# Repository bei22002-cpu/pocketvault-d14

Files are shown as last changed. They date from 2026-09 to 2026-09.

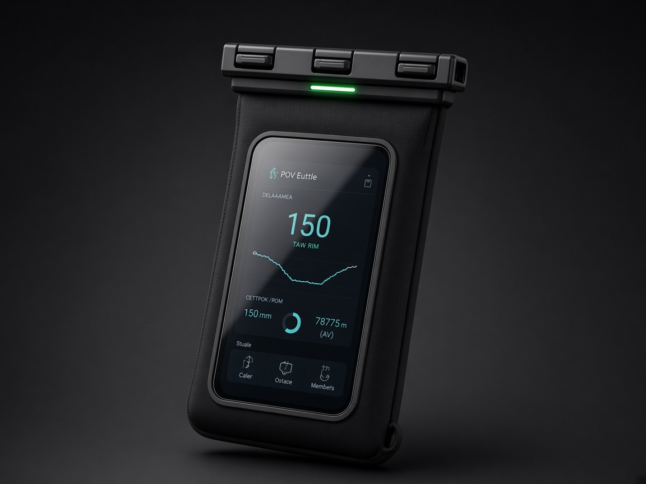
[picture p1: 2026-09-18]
blueprints/rolltop/renders/revD-hero-sealed.png

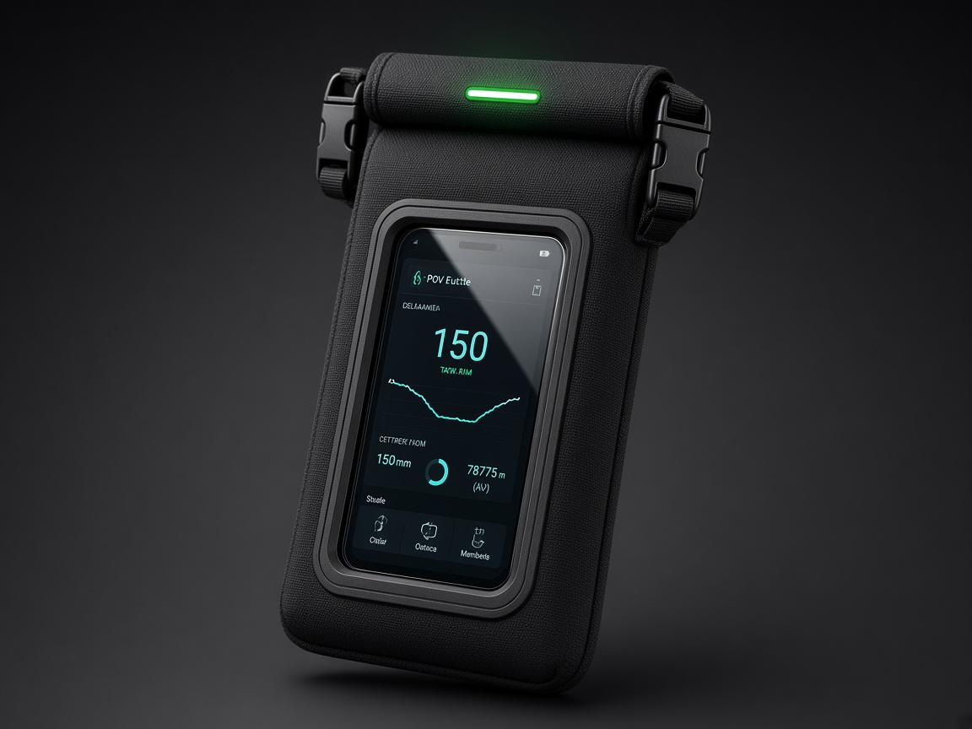
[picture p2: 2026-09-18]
blueprints/rolltop/renders/revB-hero-sealed.png

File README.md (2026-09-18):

# PocketVault · D14 Rolltop

**Live site: https://bei22002-cpu.github.io/pocketvault-d14/**

Product proposal, business model, and engineering package for the D14 Rolltop — a waterproof phone pouch you can use through the window, sold wholesale to retail stores. BYU-Idaho IBC, Oct 12 – Dec 16 window.

## Start here

| Link | What it is |
|---|---|
| [Product proposal deck](https://bei22002-cpu.github.io/pocketvault-d14/blueprints/d14-product-pitch.html) | 11 core slides + 3 appendix pages + business model canvas |
| [One-page pre-read](https://bei22002-cpu.github.io/pocketvault-d14/blueprints/d14-product-pitch-brief.html) | Decision request, trade-offs, economics, yes-vs-no. Print-ready |
| [Business model canvas](https://bei22002-cpu.github.io/pocketvault-d14/blueprints/d14-product-pitch.html#15) | Osterwalder nine-block model |
| [Blueprint gallery](https://bei22002-cpu.github.io/pocketvault-d14/blueprints/index.html) | Drawings, orthographics, BOMs, CAD downloads |
| [Speaker notes](blueprints/manufacturing/D14-PRODUCT-PITCH-NOTES.md) | Timed script, objection table, deck rationale |

## Presenting the deck

| Key | Action |
|-----|---|
| `←` `→` | Previous / next slide |
| `N` | Toggle presenter notes |
| `A` | Jump to appendix |
| `B` | Jump to business model canvas |
| `F` | Fullscreen |

The deck is a single self-contained HTML file. No build step, no dependencies beyond a webfont.

## Structure

```
index.html              Landing page
blueprints/             Site root — decks, gallery, assets
  d14-product-pitch*    Product proposal deck and pre-read
  d14-approval*         Manufacturing (P1) vote deck
  assets/ svg/ models/  Renders, orthographics, STL + STEP
  cad/                  Parametric CadQuery builder
  videos/ products/     Demo films and product shots
```

## Caveats

Renders are concept art and the drawings are pre-freeze. Unit economics are modeled planning bands (±30–50%), not factory quotes — they stay illustrative until an RFQ lands. No IP rating is claimed until certification testing is complete; waterproof language is gated on lot dunk-QC.

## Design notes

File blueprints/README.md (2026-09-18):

# Nereid Interface Catalog — Build Package

Static build blueprints + **fabricated CAD** for all **18** Nereid designs (Rev A).

## Status

| Deliverable | Count |
|---|---:|
| Concept PNG blueprints | 18 |
| SVG orthographic sheets | 18 |
| STL print files | 56 |
| STEP CAD files | 56 |
| Designs with full BOM + assembly | 18 |

## Open locally

```bash
npx --yes serve blueprints
```

Or open `blueprints/index.html` (use a local server for CAD manifest fetch).

## Rebuild 3D models

```bash
python blueprints/cad/build_all.py
```

Requires: `cadquery` (Python).

## Layout

| Path | What |
|---|---|
| `index.html` | Gallery: PNG + SVG + BOM + CAD downloads |
| `d14-product-pitch.html` | D14 product proposal — 11 core slides + 3 appendix (← → nav, `N` notes, `A` appendix, `F` fullscreen) |
| `d14-product-pitch-brief.html` | One-page pre-read / leave-behind with the yes-vs-no decision |
| `manufacturing/D14-PRODUCT-PITCH-NOTES.md` | Timed script, objection table, and why the deck is structured this way |
| `designs.js` | Dimensions, BOM, assembly |
| `assets/` | Concept blueprint PNGs |
| `svg/` | Printable orthographics |
| `models/<ID>/` | STL + STEP + MANIFEST |
| `cad/build_all.py` | Parametric CadQuery builder |
| `PRINT_GUIDE.md` | How to print and assemble |

## Shared envelope

- Phone cavity: ~147 × 71 × 8 mm class
- Rigid standard outer: ~168 × 88 × 26 mm
- Full-screen aperture: ~148 × 70 mm

Weights/depths are engineering targets. Prototypes must be pressure-tested before water use.

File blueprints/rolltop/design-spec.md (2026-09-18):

# Northstar Roll-Top Wallet — Design Spec v0.2

> **This document is the card wallet, not the phone pouch.** Two different
> products share this folder. This one is the locked v1 per `DECISION.md`: a
> 100 × 70 mm card wallet with a dry bag welded to its bottom edge, no window
> and no electronics. The window-bezel variant that `DECISION.md` parks as v1.1
> is drawing `D14-RT-003` — see `derived-dimensions-revC.md` and
> `renders/D14-RT-003-revC.png`. Do not cross-read dimensions between them.

> v0.2 reconciles this document with the parametric CAD model in `cad/`.
> Building the model corrected four things: the closure mechanism, the panel
> length, the loaded thickness and the sealed volume. See §9 for the log.

A slim everyday card wallet with a waterproof roll-top dry bag permanently
attached along one edge. Stowed, it reads as an ordinary minimalist wallet.
Deployed, it swallows a phone, keys and the wallet itself and seals watertight.

Source: hand sketch in `reference/original-sketch.png`.

---

## 1. Reading of the original sketch

| Sketch element | Interpretation carried into this spec |
| --- | --- |
| Hatched cylinder at the edge of the front view | Dry bag rolled into a compact cylinder, stowed flush against the wallet |
| Spiral in the side view | Roll cross-section, ~4–5 turns |
| Annotations "4" and circled "5" | Number of roll-downs required to seal |
| Long arm with curved arrow | Closure strap swinging over the roll to the buckle |
| Circled "1" / "2" on the flat strap | Strap and buckle hardware callouts |
| "Waterproof" | Welded-seam construction, no stitch penetrations below the waterline |

## 2. Core architecture

The wallet is the **anchor plate** for the closure. The bag welds to its full
bottom edge, and the strap that clamps the roll bar-tacks to the wallet itself,
so no separate closure hardware is needed and the roll always compresses
against a stiff flat surface.

An earlier draft of this spec claimed the wallet *was* the roll core. That is
not buildable: the wallet is 70 mm tall and stiffened with HDPE, so it cannot
wrap into a 25 mm roll. The bag's mouth rolls up against the wallet instead.

**Stowed.** The whole bag spirals into a 12.4 mm cylinder sitting flush under
the wallet's bottom edge, strap over the roll, buckle clipped on the front
face. Card slots stay accessible without unrolling.

**Deployed.** Unclip, unroll, and the bag opens downward into a 280 mm tube.
Load it, roll the mouth up against the wallet four times, and clip the strap
over the roll to compress it.

**Sealed.** 0.59 L enclosed, 176 mm of usable depth. Cards ride on the outside
in welded TPU slots; see §7 for why that is still an open question.

## 3. Dimensions

All values below are produced by `python -m cad.build`, which writes
`export/derived-dimensions.md` straight from the solid model.

### Wallet body

| Feature | Dimension |
| --- | --- |
| Width × height | 100 × 70 mm |
| Thickness, empty | 4.00 mm |
| Thickness, 6 cards + cash | 7.96 mm |
| Card capacity | 6–8 |

The 7.96 mm figure is the sum of the layer stack (0.6 shell + 0.8 stiffener +
0.6 liner + 0.2 slot film + 4.56 cards + 1.2 cash allowance). The 12 mm in v0.1
was a guess and was 50% too thick.

### Dry bag

| Feature | Dimension |
| --- | --- |
| Panel width (flat) | 100 mm — matches the wallet, so the roll sits flush |
| Panel length (unrolled) | 280 mm |
| Material consumed by the sealing roll | 104 mm |
| Usable depth when sealed | 176 mm |
| Cross-section, loaded | 100 × 35 mm, 14 mm corner radius |
| Sealed volume | 0.59 L |
| Fits | 6.9" phone (163 × 78 × 8.5), keys, cash |

Panel length is **sized backwards from the phone**: 163 mm of phone plus 12 mm
clearance plus the 104 mm the roll eats gives 279 mm, rounded to 280.

### Stowed envelope

| Feature | Dimension |
| --- | --- |
| Overall, including strap | 100 × 82 × 15.2 mm |
| Roll cylinder diameter | 12.4 mm |
| Roll turns | 10.9 |
| Target mass | ≤ 85 g |

Roll diameter is verified two ways and agrees to 0.2 mm: by conservation of
area (280 mm × 0.35 mm pitch spiralled around a 2.2 mm core) and by measuring
the bounding box of the swept solid.

## 4. Materials and BOM

| # | Part | Material | Notes |
| --- | --- | --- | --- |
| 1 | Bag body | 70D nylon, 0.10 mm TPU lamination both faces, ~140 g/m² | RF-weldable, must be TPU not PVC for cold-crack and recyclability |
| 2 | Wallet shell | X-Pac VX21 or 210D recycled nylon with TPU face | Matte charcoal, abrasion resistant |
| 3 | Wallet stiffener | 0.8 mm HDPE sheet | Encapsulated, gives the roll its batten |
| 4 | Card slots | 0.2 mm clear/black TPU film | Welded, not stitched |
| 5 | Lip batten | 1.5 mm semi-rigid TPU rod in welded channel | Keeps the mouth flat so the roll seals evenly |
| 6 | Strap | 15 mm nylon webbing | Bar-tacked above the waterline only |
| 7 | Buckle | 15 mm acetal side-release, low-profile (Duraflex Stealth class) | Matte black, no logo |
| 8 | Seams | 10 mm RF-welded lap | No stitching below the fold line |

Colourway: charcoal-black wallet, deep ocean blue bag, matte black hardware.

## 5. Construction sequence

1. Weld card slots to the wallet inner panel.
2. Encapsulate the HDPE stiffener between wallet outer and inner panels; weld
   the perimeter on three sides.
3. Weld the bag panel's top edge into the wallet's open fourth edge — this is
   the single critical joint and it is a continuous lap weld, never a seam.
4. Weld bag side seams, 10 mm lap, bottom corners boxed and radiused.
5. Weld the batten channel at the bag mouth, insert TPU rod, cap both ends.
6. Bar-tack the clamp strap to the wallet back face at Z=30 mm, and the buckle
   tab to the front face at Z=58 mm. These are the only two stitch lines.
7. Attach buckle halves; heat-seal webbing ends.

## 6. Waterproofing strategy

The only stitch penetrations are the two bar-tacks that anchor the clamp strap
and the buckle tab. Both sit on the wallet at Z=30 mm and Z=58 mm, well above
the roll line, therefore above the waterline. Everything below is welded.

Target claim: **IPX7 — 1 m submersion, 30 minutes, with 4 rolls buckled.**
This is a target, not a verified rating. Validate before it goes on packaging.

Test plan:

- Static submersion, 1 m / 30 min, 3 and 4 rolls, tissue-paper witness inside.
- Roll-count sensitivity: find the minimum rolls that hold, publish rolls + 1.
- Weld peel strength on the wallet-to-bag joint, before and after cycling.
- 5,000-cycle roll/unroll fatigue at the fold line — this is the likely failure
  point, as repeated creasing at a fixed radius will eventually craze the TPU.
- Cold-crack at −20 °C.
- 72 h UV exposure, check for embrittlement and colour shift.

## 7. Open risks

- **Fold-line fatigue.** The bag always creases in roughly the same place.
  Consider a slightly softer, thinner laminate in a 20 mm band at the fold, or
  a deliberately varied roll start point.
- **Wallet-to-bag weld.** Dissimilar materials (X-Pac face vs TPU bag) may not
  weld reliably. Fallback is a common TPU carrier strip welded to both.
- **Stowed bulk.** 15.2 mm including the wrapped strap, 12.4 mm at the roll
  alone. Fine for a front pocket, tight for a back pocket. The roll diameter
  scales directly with panel length, so any extra depth costs bulk: the
  280 mm panel needed to fit a phone already added 1 mm over the first draft.
- **Cards when sealed.** They ride outside the dry volume. Acceptable if the
  welded slots hold, but worth prototyping a variant where the wallet inverts
  inward and rides inside the seal.
- **Bag depth when stowed.** The 35 mm loaded cross-section is what a phone
  plus keys needs, but the roll maths assumes the bag flattens to two plies.
  Confirm on a mock-up that a 35 mm bag rolls down to 12.4 mm cleanly.

## 8. Next steps

1. Paper/tape mock-up at full scale to confirm roll diameter and the 4-roll
   usable depth.
2. Source a TPU laminate swatch set; run weld trials for part 3 above.
3. Soft prototype, then run the section 6 test plan.
4. Resolve the cards-outside-the-seal question before tooling the buckle.

## 9. What the CAD model changed

Building `cad/` falsified four claims in v0.1. Each was caught by a test or by
measuring a solid, not by opinion.

| v0.1 claim | v0.2 | Why |
| --- | --- | --- |
| Wallet is the roll core | Wallet is the anchor plate | A 70 mm stiffened panel cannot roll into a 25 mm closure |
| Panel 105 × 230 mm | 100 × 280 mm | 230 mm left 126 mm usable — a 163 mm phone did not fit. 105 mm made the roll overhang the wallet |
| Loaded thickness 12 mm | 7.96 mm | Derived from the layer stack instead of guessed |
| Sealed volume 1.1 L | 0.59 L | Computed on the true rounded cross-section |

Unchanged and now confirmed by measurement: the 100 × 70 mm wallet, the 4.00 mm
empty stack, the ~82 mm stowed height, and the roll diameter agreeing with the
conservation-of-area calculation to within 0.2 mm.

---

## Renders

- `renders/hero-render.png` — stowed and deployed states
- `renders/construction-diagram.png` — side-profile cross-section and front elevation
- `renders/deployment-sequence.png` — four-step stow → unroll → load → seal

## CAD

See [`docs/cad.md`](cad.md). Build with `python -m cad.build`.

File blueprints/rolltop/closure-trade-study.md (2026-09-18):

# D14 closure trade study — is the roll-top right at 10 m?

Generated by `closure_trade.py`. Rated depth 10 m, internal pressure 101 kPa, mouth width 119 mm.

> **Acted on.** The recommendation below is built as Rev D, drawing `D14-RT-004`. Rev D moved the latches inboard of the mouth ends rather than onto them, which cut the span and took the bar from the 8.0 mm assumed here down to 6.0 mm.

## Seal load: the bar asks for less

Both closures have to hold 3x internal pressure across their contact strip, so the load follows the strip width. A 6 mm bar face needs 1.81 N/mm, or 215 N across the mouth, against the 287 N the roll needs over its wider 8 mm bundle — 25% less clamp for the user to generate. A narrow, well-defined seal line is cheaper to load than a wide, vague one.

## What sizes a clamped bar

A bar seals only if it stays flat against the gasket between its latches. With a 1.5 mm bead compressed 30%, the squeeze is 0.45 mm, and spending more than 25% of that on mid-span bow means the centre of the mouth is sealing on less than the ends. That caps bow at 0.112 mm and is the binding constraint.

| Material | Latches | Span | Bar thickness | Mass | Bending stress |
| --- | --- | --- | --- | --- | --- |
| PPA GF30 | 2 | 130 mm | 20.1 mm | 32.5 g | 7.1 MPa |
| PA66 GF50 | 2 | 130 mm | 17.8 mm | 31.8 g | 9.1 MPa |
| 6061-T6 aluminium | 2 | 130 mm | 10.9 mm | 30.7 g | 24.0 MPa |
| PPA GF30 | 3 | 65 mm | 8.0 mm | 12.9 g | 11.2 MPa |
| PA66 GF50 | 3 | 65 mm | 7.1 mm | 12.6 g | 14.4 MPa |
| 6061-T6 aluminium | 3 | 65 mm | 4.3 mm | 12.2 g | 38.2 MPa |

Deflection governs everywhere — peak stress never exceeds 38 MPa against flexural strengths in the hundreds, so these bars are stiffness-limited, not strength-limited. Three consequences:

- **Material barely matters.** Every two-latch bar lands between 31 and 32 g whatever it is made of, because stiffness goes as thickness cubed while mass goes as thickness times density, and the two effects very nearly cancel across this material set. Choosing aluminium buys a thinner bar, not a lighter one.
- **Two latches does not work in plastic.** A PPA bar latched only at its ends needs to be 20 mm thick, which is thicker than the whole 18.5 mm pouch. Span enters as the fourth power, so this is not a small miss.
- **Either add a third latch or go metal.** A centre latch halves the span and drops the PPA bar to 8.0 mm and 13 g. Keeping two latches and switching to aluminium gives 10.9 mm and 31 g.

## Mass and material, bar against roll

| Item | Roll-top | Clamped bar, 3 latches |
| --- | --- | --- |
| Closure hardware | 16.7 g | 12.9 g + 3 latches |
| Mouth material consumed | 78 mm | 25 mm |
| Fabric saved | — | 6.2 g |
| Net mass change | — | -10.0 g before latches |

## The reason to switch is not mass

Mass is a wash. The case for the bar is that it changes the character of the leak path and the honesty of the sensing:

- **Leak path.** A roll seals along a spiral, and the ends of that spiral are where dry bags actually leak: the folded edges form a small channel that no amount of strap tension closes. A bar seals along a straight line against a defined gasket, which is a geometry you can inspect, measure and calculate.
- **Creep.** Roll contact pressure is carried by TPU-faced fabric in sustained compression, which relaxes. A 10 m rating held for 30 minutes is exactly the duration over which that relaxation matters, and it is not something the load cells can correct for once the user has walked away from the buckle.
- **Sensing fidelity.** This is the strongest argument. On the roll, the cells read strap tension through a compressible 10 mm bundle, so they infer interface pressure through the most compliant element in the stack. On a bar, the cells sit directly in the load path under the gasket line. The clamp-verification feature the whole product is named for only measures what it claims to measure in the bar version.

## What the bar costs

- A second rigid part, roughly mouth-width, that does not collapse. The `designs.js` warning that the hard bezel edge is an impact weak point now applies to the bar as well.
- Grit tolerance goes down, not up. A roll closes over sand; a gasket does not. For a beach and boat-deck product that is a real regression and argues for a wipeable, exposed gasket land rather than a recessed groove.
- Three latches is three user actions instead of two, and a centre latch is easy to forget.

## Recommendation

Move to a clamped bar with a centre latch, 8.0 mm in PPA GF30, and keep the four load cells but relocate them into the bar and its land. It is mass-neutral, it turns a spiral friction seal into a straight gasket line, and it makes the sensing measure the seal instead of a proxy for it. If the third latch tests badly with cold hands, the fallback is two latches with the 10.9 mm aluminium bar at 31 g.

The rigid gasketed lid is not carried forward. At this mouth width it is a rigid case top, which ends the soft-body premise that puts D14 in the non-rigid family at all. If the programme wants a genuine 10 m gasketed closure, the honest move is to build an A-family rigid case, not to armour a pouch until it becomes one.

## Still unproven

- The 0.112 mm bow budget is an assumption about how unevenly a gasket can be loaded before it leaks. It needs a bench test on a bar with a deliberately sloppy centre latch.
- Nothing here changes the fact that the bezel-to-body weld and the glass bond are still the two longest unvalidated seal paths on the product. The closure is not the only risk, and fixing it does not make the pouch waterproof on its own.

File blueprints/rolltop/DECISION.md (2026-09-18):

# Product decision — locked

**Date:** 2026-09-18  
**Decision:** Ship the **roll-up bag** (wallet + permanently attached roll-top dry bag).  
**Brand for IBC:** PocketVault Roll-Up  
**Source design:** `Northstar/Wallet` (sketch → spec → CadQuery)

## What we are not shipping in v1

- Rigid dive-phone cases from the Nereid A/B/C families (kept as R&D catalog).
- Clear touchscreen window / load-cell bezel (Nereid D14). Parked as **v1.1** if dunk demos prove sealed phone-use is required to convert.

## Why

1. **Availability:** always on-body with cards — beats “remember a dry bag.”
2. **Survey fit:** waterproof is #1; $15–$25 price band; campus outdoor use.
3. **Buildable:** CAD, BOM, and dunk test plan already exist in Wallet.

## Next actions

1. Supplier quotes for TPU roll-top + wallet shell (50 / 100 / 250).
2. Physical mock-up → dunk video.
3. Preorder page at $14.99 early-bird / $19.99 list.
4. Close survey phone leads with roll-up photos + reserve ask.

## Links

- Product page: `blueprints/rolltop.html`
- Spec: `blueprints/rolltop/design-spec.md`
- Film (soft-goods cousin): `blueprints/videos/products/D14-rolltop.mp4`

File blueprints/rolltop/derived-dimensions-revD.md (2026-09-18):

# D14 CLAMP-BAR — derived dimensions, Rev D

Generated by `rev_d_dimensions.py` for drawing D14-RT-004. Rev D replaces the three-fold roll with a bar clamping the mouth against a gasket land, per `closure-trade-study.md`. Rev C is retained unchanged as the record.

**The name no longer describes the product.** `designs.js` still calls D14 *Rolltop*, and there is no roll in Rev D. That designation needs a decision before this reaches the catalogue.

## Window and glazing (carried from Rev C)

| Dimension | Value | Derivation |
| --- | --- | --- |
| Window clear aperture, width | 74.0 mm | display 70.0 + 2 x 2.0 registration tolerance |
| Window clear aperture, height | 156.0 mm | display 152.0 + 2 x 2.0 registration tolerance |
| Glass thickness | 3.0 mm | next standard pane above the 2.92 minimum |
| Pane bending stress at proof | 114.0 MPa | pane bending stress at proof depth |
| Pane centre deflection at proof | 0.535 mm | centre deflection at proof |
| Air gap, pane to display | 1.5 mm | exceeds the 0.54 proof deflection |

## Rigid bezel

| Dimension | Value | Derivation |
| --- | --- | --- |
| Bezel body width | 89.0 mm | pane + 2 x 4.5 frame face |
| Bezel body height | 171.0 mm | pane + 2 x 4.5 frame face; no electronics rail, they moved to the closure |
| Bezel body thickness | 8.0 mm | rigid frame body thickness |
| Weld flange width | 105.0 mm | bezel + 2 x 8.0 weld flange |
| Weld flange height | 187.0 mm | bezel + 2 x 8.0 weld flange |

## Clamp-bar closure

| Dimension | Value | Derivation |
| --- | --- | --- |
| Clamped mouth width | 119.0 mm | the mouth clamps flat, so it is the flat panel width |
| Required seal line load | 1.81 N/mm | 3 x internal pressure over a 6 mm gasket face |
| Total clamp force | 215.4 N | line load x mouth width |
| Clamp force per latch and cell | 71.8 N | seal-verify threshold, 3 latches each over a load cell |
| Latches | 3 | usability ceiling; a fourth latch is one more thing to forget |
| Span between latches | 51.5 mm | latches inset 8.0 from each end, 2 equal spans |
| Gasket squeeze at full clamp | 0.450 mm | 1.5 bead at 30% |
| Allowable mid-span bow | 0.112 mm | 25% of the squeeze |
| Bar second moment required | 134 mm4 | I = 5wL^4/(384 E delta) |
| Bar thickness minimum | 5.9 mm | I = face_z * h^3 / 12, solved for h |
| Bar thickness specified | 6.0 mm | next standard section above the 5.86 minimum |
| Mid-span bow at specified section | 0.105 mm | bow at the specified section |
| Bow at the outboard overhang | 0.00059 mm | cantilever bow at the 8.0 mm outboard overhang |
| Bar peak bending stress | 12.5 MPa | peak bending stress; deflection governs, not strength |
| Bar length | 119.0 mm | bar spans the full clamped mouth |
| Closure land height | 14.0 mm | closure land: houses 3 load cells, PCB, flat cell and the LED |
| Closure land thickness | 6.0 mm | land thickness through the pouch |
| Closure height above the seal line | 21.0 mm | land 14.0 + folded mouth 1.0 + bar 6.0 |

## Body and envelope

| Dimension | Value | Derivation |
| --- | --- | --- |
| Finished flat width | 119.0 mm | weld flange + 2 x 7.0 fabric margin |
| Cavity depth | 203.0 mm | flange height + 8.0 to the seal line + 8.0 to the bottom fold |
| Cavity depth spare over the device | 38.0 mm | spare depth over the device |
| Cavity thickness, loaded | 14.0 mm | air gap 1.5 + device 11.0 + rear clearance 1.5 |
| Body width, loaded | 111.0 mm | weld flange + fabric bulge either side |
| Overall width at the closure | 123.0 mm | widest point is the clamped mouth, not the body |
| Overall height, sealed | 224.0 mm | cavity depth + the closure standing above it |
| Overall thickness, sealed and loaded | 18.5 mm | section stack from the bezel face to the outside of the rear ply |
| Thickness, empty and flat | 9.0 mm | rigid bezel + collapsed body, empty |
| Thickness at the closure | 13.0 mm | closure does not collapse |
| Panel length per face, flat | 228.0 mm | cavity depth + 25.0 mouth fold |
| Cut panel width | 139.0 mm | finished width + 2 x 10.0 side lap weld |
| Cut panel length | 456.0 mm | single panel folded at the bottom |
| Mass, empty | 224.5 g | sum of the mass budget |
| Seawater displaced | 386.1 g | seawater displaced, as mass |
| Net buoyancy with device | -78.4 g | positive floats; negative sinks |

## Mass budget

| Item | Mass |
| --- | --- |
| Tempered glass pane | 96.4 g |
| Bezel frame, PPA GF30 | 38.3 g |
| Bezel weld flange, TPU | 6.4 g |
| Body laminate | 26.6 g |
| Retention sleeve, TPU film | 10.3 g |
| Clamp bar, PPA GF30 | 8.9 g |
| Closure land, PPA GF30 | 9.5 g |
| Land end caps x2 | 0.5 g |
| Gasket, silicone bead | 0.2 g |
| Over-centre latches x3 | 9.0 g |
| Load cells x3 | 3.6 g |
| MCU + BLE PCB | 4.5 g |
| Battery, 120 mAh LiPo | 2.8 g |
| Seal-status LED + potting | 2.5 g |
| Flex + wiring | 2.0 g |
| Adhesive and weld consumables | 3.0 g |
| **Total, empty** | **224 g** |

## Rev C to Rev D

| Quantity | Rev C, roll-top | Rev D, clamp bar | Note |
| --- | --- | --- | --- |
| Clamp force | 287 N total | 215 N total | 25% less for the user to generate |
| Per sensor | 72 N over 4 | 72 N over 3 | near-identical threshold, one fewer cell |
| Bezel height | 180.5 mm | 171.0 mm | electronics left the bezel, so the top rail became a frame face |
| Cavity depth | 212.5 mm | 203.0 mm | follows the shorter bezel |
| Mouth material | 78 mm | 25 mm | one fold instead of three |
| Sealed height | 223.7 mm | 224.0 mm | +0.3 mm |
| Overall width | 111 mm | 123 mm | the clamped mouth is now the widest point |
| Mass, empty | 225 g | 224 g | -1 g |
| Net buoyancy | -76 g | -78 g | still sinks; tether required |

## What the calculation actually decided

- **Span, not material.** Bow goes as span to the fourth power. Moving the latches inboard cut the span to 51.5 mm and the bar to 6.0 mm; the two-end-latch arrangement in the trade study needed 20 mm in the same plastic. No material change comes close to that.
- **The overhang is free.** The 8 mm outboard of the end latches bows 0.00059 mm, which is nothing, because cantilever deflection also goes as the fourth power and the overhang is short. That is what makes inboard latches viable at all.
- **The bar is stiffness-limited by a wide margin.** Peak stress is 12.5 MPa against a flexural strength in the hundreds. Nothing here is close to breaking; it is only about staying flat.
- **Relocating the electronics paid for the closure.** Taking the load cells and PCB out of the bezel shortened it by 9.5 mm, which very nearly offsets the 21 mm the closure adds. The product ends up 0.3 mm taller than Rev C, which is nothing. A better closure came out mass- and size-neutral, exactly as the trade study predicted.

## Still open

- **Load cells under latches cannot see mid-span bow.** Each cell reports what its own latch delivered. The 0.112 mm bow budget is therefore a design guarantee, not a sensed quantity, and a cracked or over-compliant bar would read as fully sealed.
- **Grit is a regression.** A roll closes over sand; a gasket does not. The land needs a wipeable, exposed sealing face rather than a groove that traps debris.
- **The bezel weld and the glass bond are unchanged and still the longest unvalidated seal paths on the product.** Rev D fixes the closure only. The pouch is not waterproof until all three joints are tested.
- Nothing has been submerged. The depth rating remains a design target pending proof and dunk testing.

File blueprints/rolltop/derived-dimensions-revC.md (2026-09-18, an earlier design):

# D14 Rolltop — derived dimensions, Rev C

Generated by `rev_c_dimensions.py` for drawing D14-RT-003. Do not edit by hand; change the inputs at the top of that script instead.

> **Superseded by Rev D.** The roll-top closure below was replaced by a clamped bar per `closure-trade-study.md`; see `derived-dimensions-revD.md` and drawing `D14-RT-004`. Rev C is kept as the record of how the roll was sized, and its window, glazing and section stack carry forward unchanged.

## Datum

| Quantity | Value | mm |
| --- | --- | --- |
| Device class | 6.9 in flagship, bare | 163.0 x 77.6 x 8.3 |
| Device with slim case | accommodated | 165.0 x 80.0 x 11.0 |
| Display active area | exposed in full | 152.0 x 70.0 |
| Rated depth | 10 m for 30 min | — |
| Proof depth | 30 m | — |

## Window and glazing

| Dimension | Value | Derivation |
| --- | --- | --- |
| Window clear aperture, width | 74.0 mm | display 70.0 + 2 x 2.0 registration tolerance |
| Window clear aperture, height | 156.0 mm | display 152.0 + 2 x 2.0 registration tolerance |
| Aperture aspect a/b | 2.108 | long span / short span, drives the plate coefficients |
| Glass minimum thickness required | 2.9 mm | t = sqrt(beta*q*b^2/sigma_allow) at proof, sigma_allow = 120 MPa |
| Glass thickness specified | 3.0 mm | next standard pane above the 2.92 minimum |
| Pane width | 80.0 mm | aperture + 2 x 3.0 bonded seat land |
| Pane height | 162.0 mm | aperture + 2 x 3.0 bonded seat land |
| Bezel rebate depth | 3.3 mm | pane thickness + adhesive bead |
| Pane bending stress at rated depth | 38.0 MPa | bending stress at 10 m |
| Pane bending stress at proof depth | 114.0 MPa | bending stress at 30 m proof |
| Pane centre deflection at rated depth | 0.2 mm | centre deflection at rated depth |
| Pane centre deflection at proof depth | 0.5 mm | centre deflection at proof |
| Air gap, pane to display | 1.5 mm | exceeds the 0.54 proof deflection, so the pane never touches the display |

## Rigid bezel

| Dimension | Value | Derivation |
| --- | --- | --- |
| Bezel body width | 89.0 mm | pane + 2 x 4.5 frame face |
| Bezel body height | 180.5 mm | pane + 4.5 frame face below + 14.0 electronics rail above |
| Electronics rail height | 14.0 mm | houses 4 load cells, PCB, battery and the status LED |
| Bezel body thickness | 8.0 mm | rigid frame body thickness |
| Weld flange width | 105.0 mm | bezel + 2 x 8.0 weld flange |
| Weld flange height | 196.5 mm | bezel + 2 x 8.0 weld flange |

## Soft body

| Dimension | Value | Derivation |
| --- | --- | --- |
| Finished flat width | 119.0 mm | weld flange + 2 x 7.0 fabric margin |
| Cavity depth, seal line to bottom fold | 212.5 mm | flange height + 8.0 to the seal line + 8.0 to the bottom fold |
| Cavity depth spare over the device | 47.5 mm | spare depth over the device; the bezel flange sets the cavity, not the phone |
| Cavity thickness, loaded | 14.0 mm | air gap 1.5 + device 11.0 + rear clearance 1.5 |
| Internal clear width | 101.0 mm | fabric wraps just inboard of the weld flange edge; the bezel holds the front face flat |
| Clearance either side of the device | 10.5 mm | clear either side of the device inside the cavity |
| Overall width, loaded | 111.0 mm | weld flange + fabric bulge either side |
| Panel length per face, flat | 290.5 mm | cavity depth + material the roll consumes |
| Cut panel width | 139.0 mm | finished width + 2 x 10.0 side lap weld |
| Cut panel length | 580.9 mm | single panel folded at the bottom, so no bottom seam |

## Roll closure

| Dimension | Value | Derivation |
| --- | --- | --- |
| Roll bundle diameter, free | 10.0 mm | 4.0 batten core + 3 folds, each adding 2.0 (two plies of 0.5 top and bottom) |
| Panel length consumed by the roll | 78.0 mm | sum of 3 turn circumferences (66.0) + 12.0 batten channel hem |
| Roll thickness, clamped | 7.0 mm | free diameter compressed to 70% under the clamp straps |
| Roll depth, clamped | 11.2 mm | section area preserved as the bundle flattens |
| Required roll contact pressure | 0.302 MPa | 3 x internal pressure at 10 m |
| Roll contact patch | 952.0 mm2 | strap bearing width x roll length |
| Total clamp force to verify seal | 287.2 N | contact pressure x contact patch |
| Clamp force per load cell, minimum | 71.8 N | seal-verify threshold, 4 cells sharing the clamp |
| Clamp force per load cell, maximum | 200.0 N | upper limit before the bezel top rail is over-stressed |

## Envelope, mass and buoyancy

| Dimension | Value | Derivation |
| --- | --- | --- |
| Overall height, sealed | 223.7 mm | cavity depth + the clamped roll standing above it |
| Overall thickness, sealed and loaded | 18.5 mm | section stack from the bezel face to the outside of the rear ply |
| Thickness, empty and flat | 9.0 mm | rigid bezel + collapsed body, empty |
| Thickness, empty, at the stored roll | 16.0 mm | thickest point when stored rolled |
| Mass, empty | 225.4 g | sum of the mass budget |
| Displaced volume, loaded | 379,631 mm3 | loaded section swept over the cavity depth, plus the clamped roll bundle |
| Seawater displaced | 389.1 g | seawater displaced, as mass |
| Net buoyancy with device | -76.3 g | positive floats; negative sinks and needs the tether or a float collar |

## Mass budget

| Item | Mass |
| --- | --- |
| Tempered glass pane | 96.4 g |
| Bezel frame, PPA GF30 | 41.9 g |
| Bezel weld flange, TPU | 6.6 g |
| Body laminate | 33.9 g |
| Retention sleeve, TPU film | 10.3 g |
| Mouth batten, TPU | 1.7 g |
| Clamp webbing x2 | 4.0 g |
| Side-release buckles x2 | 11.0 g |
| Load cells x4 | 4.8 g |
| MCU + BLE PCB | 4.5 g |
| Battery, 120 mAh LiPo | 2.8 g |
| Seal-status LED + potting | 2.5 g |
| Flex + wiring | 2.0 g |
| Adhesive and weld consumables | 3.0 g |
| **Total, empty** | **225 g** |

## Findings that change the design

- **The loaded pouch sinks.** It displaces 389 g of seawater and weighs 465 g with a device in it, so net buoyancy is -76 g. The wrist tether is not an accessory, it is the retention system. A float collar in the D16 pattern is the alternative.
- **The bezel sets the cavity, not the phone.** The weld flange is 196 mm tall, which forces a 212 mm cavity for a 165 mm device — 48 mm of depth that carries no payload. This is the direct cost of a display-sized rigid window.
- **Glass dominates the mass budget** at 96 g of 225 g. Dropping the pane to 2.9 mm, the calculated minimum, would save about a fifth of the total, at the cost of impact margin on a boat deck.
- **Clamp threshold is derived, not chosen.** 72 N per cell comes from holding 3x internal pressure across the roll contact patch. It still has to survive a dunk test before it goes in firmware.

## Reconciliation

| Quantity | Rev B sheet | designs.js Rev A | Rev C | Why it moved |
| --- | --- | --- | --- | --- |
| Window clear | 100 x 80 | 148 x 70 aperture | 156 x 74 | sized to the full display plus registration tolerance |
| Glass thickness | 3.0 | 1.5 | 3.0 | 3.0 confirmed by plate calculation; minimum was 2.92 |
| Body outer | 130 x 150 | 175 x 95 x 40 | 111 x 224 x 18.5 | derived from the bezel flange and the section stack |
| Depth rating | 5 m / 30 min | 6 m | 10 m / 30 min, 30 m proof | directed change |
| Mass | 225 g est. | 122 g | 225 g | itemised budget, not an estimate |
| Clamp threshold | 100 N/corner | — | 72 N/corner | derived from roll contact mechanics |

## Still open

- The bezel is PPA GF30 and the body is TPU-faced aramid. Those do not RF-weld to each other, which is why the bezel carries an overmoulded TPU weld lip. Weld trials are unproven.
- Every number above is geometry and hand calculation. Nothing has been submerged. The depth rating is a design target until the dunk and proof tests are run.
- Capacitive touch through a 3.0 mm glass pane with a 1.5 mm air gap does not work. Rev C is
  view-only through the window; all input has to come from elsewhere.

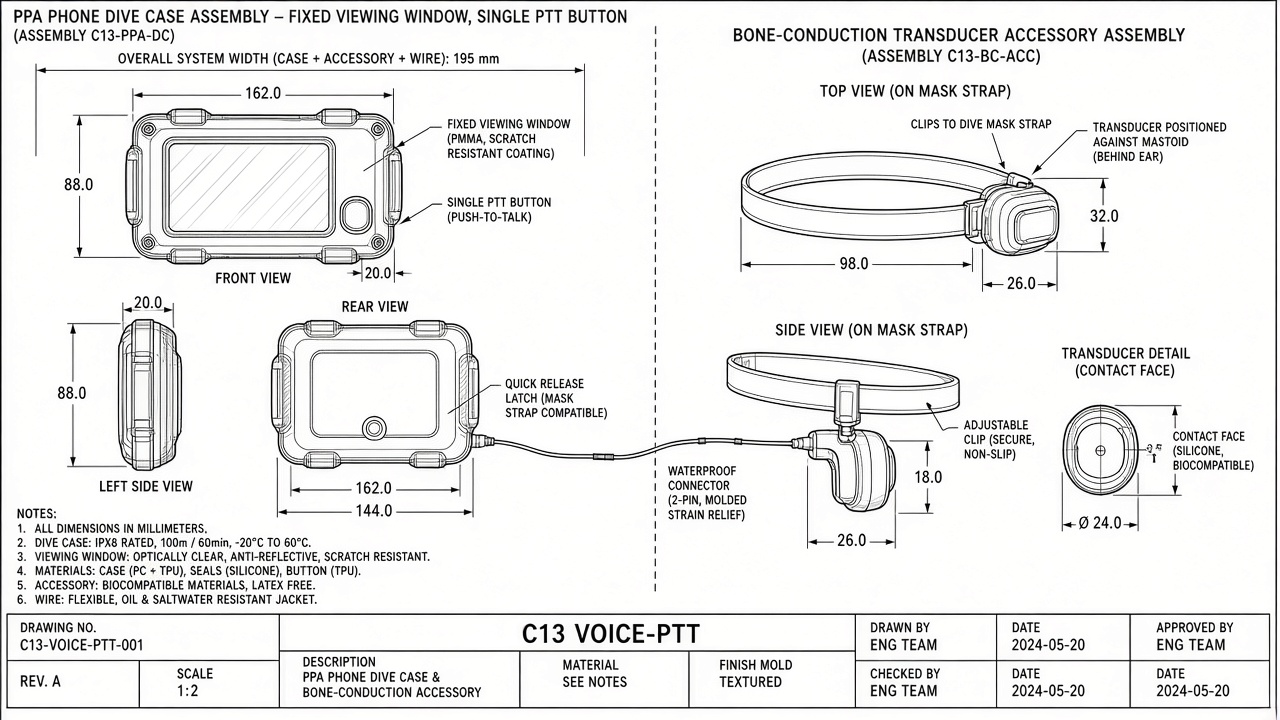
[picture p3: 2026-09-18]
blueprints/assets/C13-voice-ptt-blueprint.png

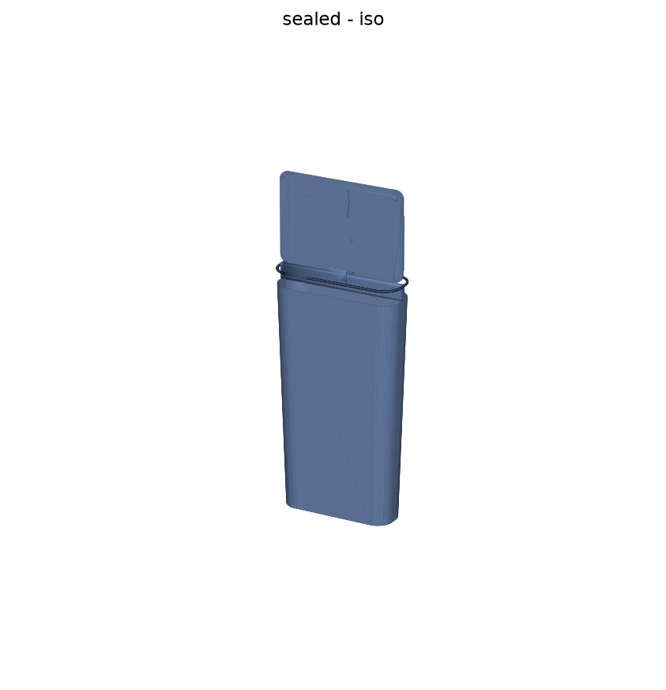
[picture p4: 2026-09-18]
blueprints/rolltop/renders/northstar_wallet_sealed_iso.png

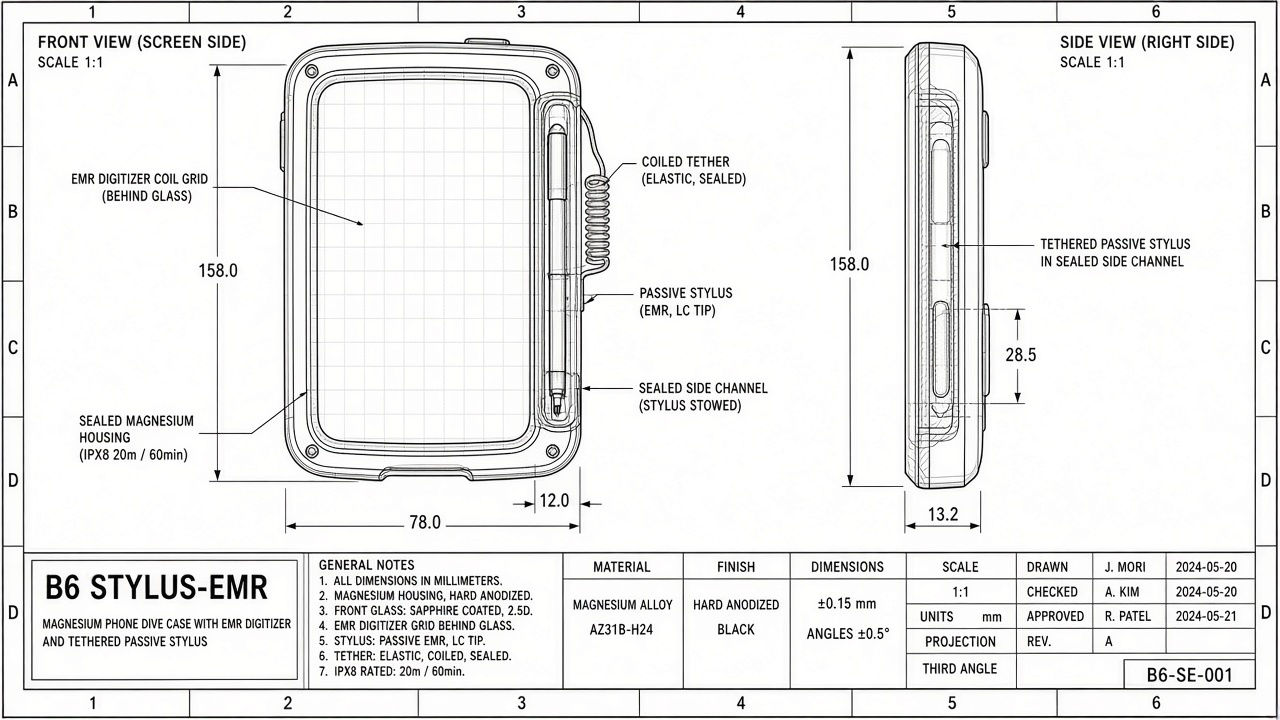
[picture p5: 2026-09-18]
blueprints/assets/B6-stylus-emr-blueprint.png

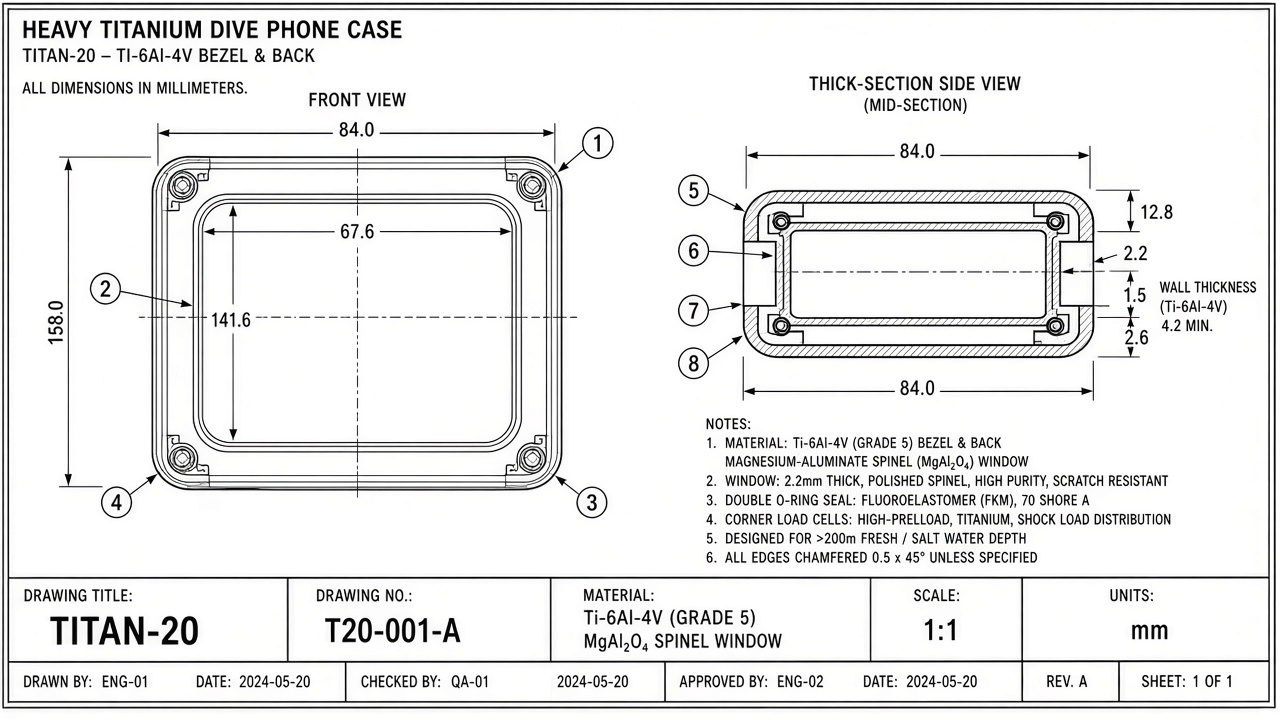
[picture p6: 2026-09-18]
blueprints/assets/A4-titan-20-blueprint.png

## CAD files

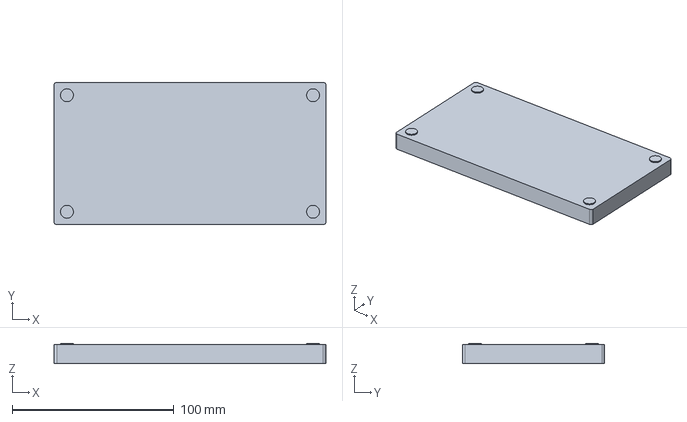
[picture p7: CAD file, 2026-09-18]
blueprints/models/A1/shell_back.step
168.0 x 88.0 x 12.4 mm

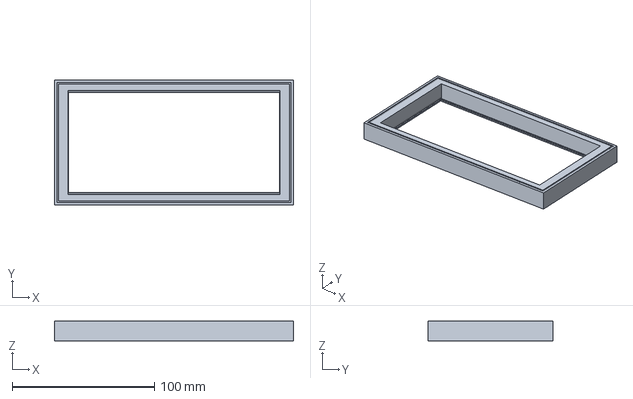
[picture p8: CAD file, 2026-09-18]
blueprints/models/A2/shell_front.step
168.0 x 88.0 x 13.8 mm

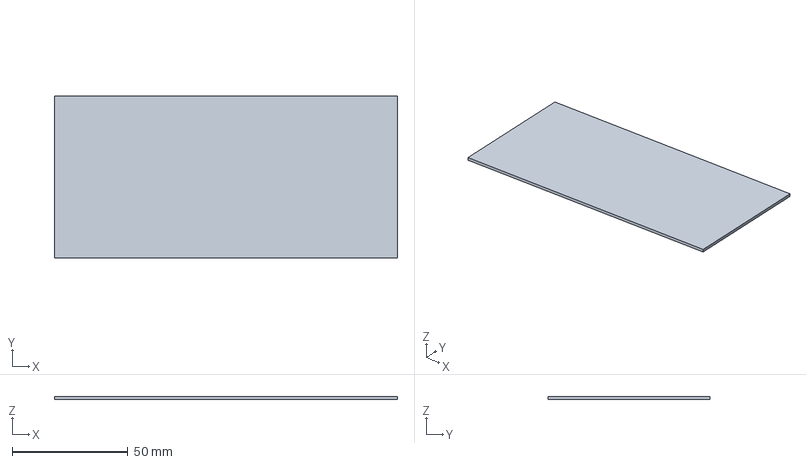
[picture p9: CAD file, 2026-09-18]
blueprints/models/A3/window_blank.step
148.0 x 70.0 x 1.50 mm

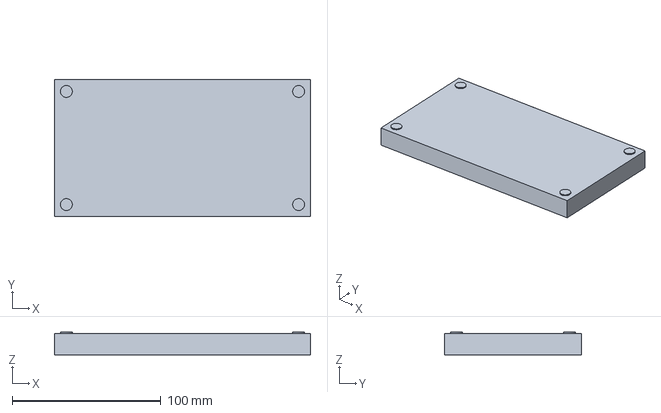
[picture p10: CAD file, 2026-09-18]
blueprints/models/A4/shell_back.step
172.0 x 92.0 x 15.2 mm

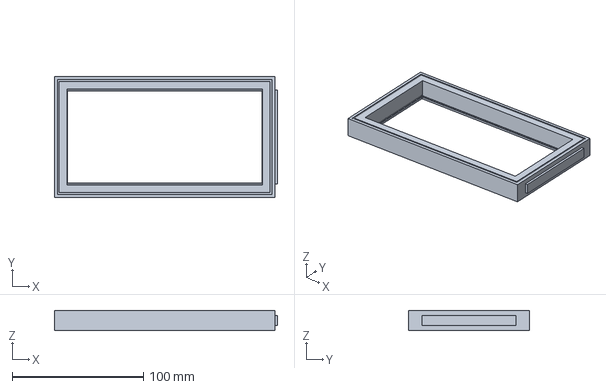
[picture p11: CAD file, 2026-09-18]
blueprints/models/B6/shell_front.step
170.0 x 92.0 x 15.4 mm

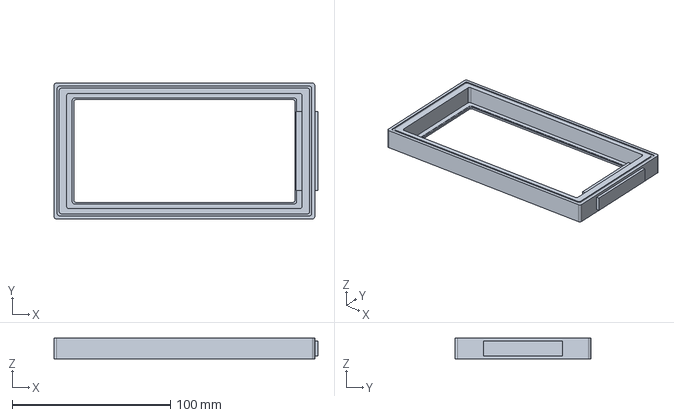
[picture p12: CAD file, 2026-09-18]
blueprints/models/C10/shell_front.step
167.0 x 86.0 x 13.2 mm

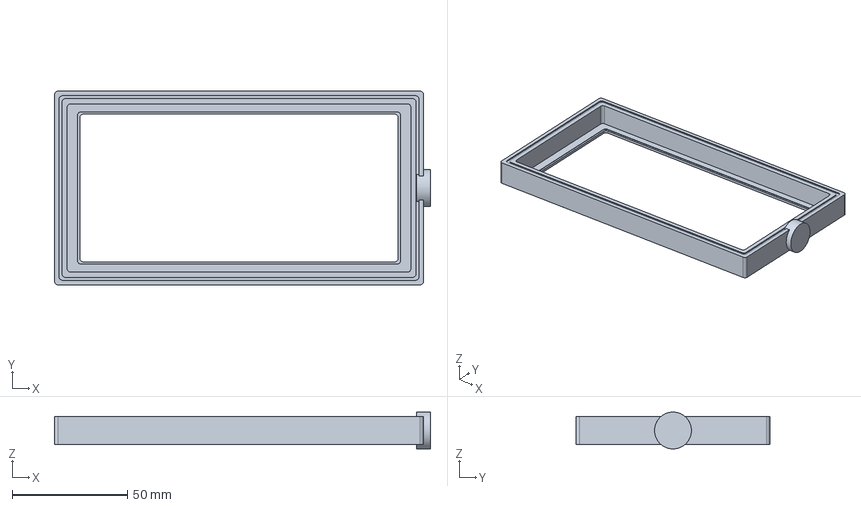
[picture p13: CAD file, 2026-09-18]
blueprints/models/C11/shell_front.step
163.0 x 84.0 x 16.0 mm

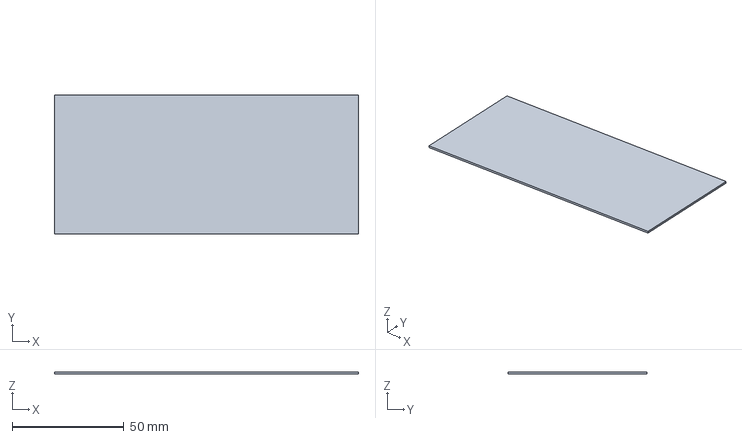
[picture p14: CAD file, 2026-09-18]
blueprints/models/C12/window_blank.step
136.0 x 62.0 x 1.00 mm

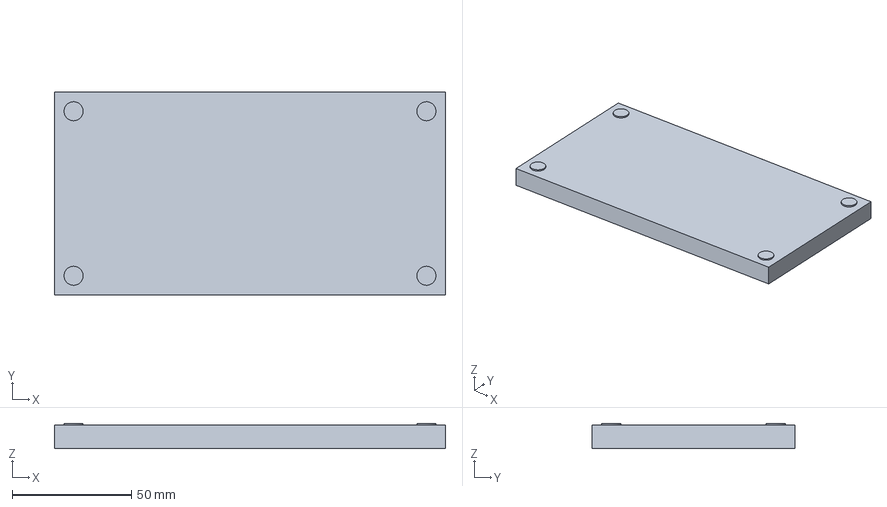
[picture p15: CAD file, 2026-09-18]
blueprints/models/C13/shell_back.step
164.0 x 85.0 x 10.7 mm

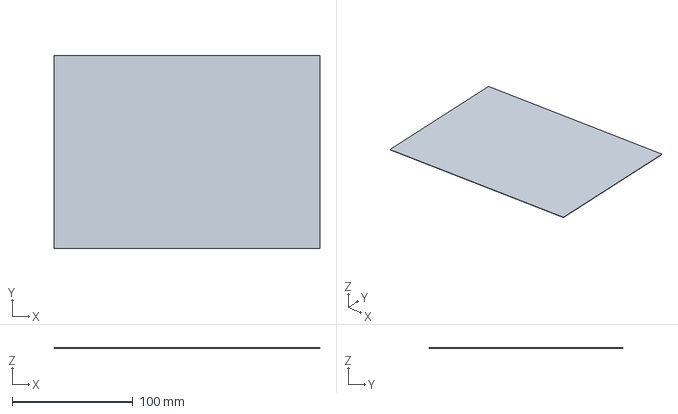
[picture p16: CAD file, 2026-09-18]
blueprints/models/D14/fabric_cut_pattern.step
220.0 x 160.0 x 0.4 mm

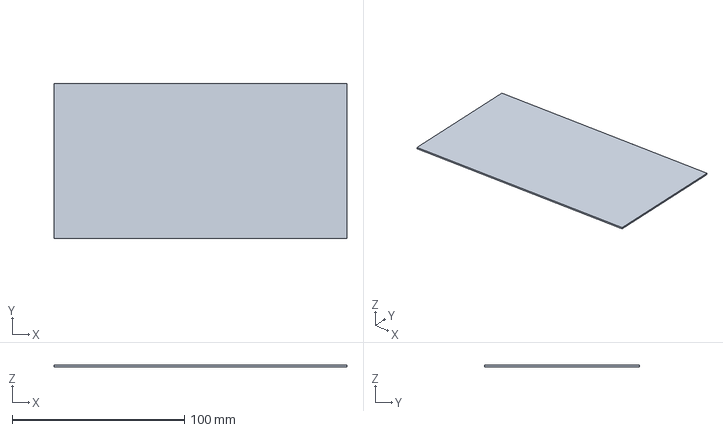
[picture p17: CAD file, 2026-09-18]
blueprints/models/D15/oil_lid.step
170.0 x 90.0 x 1.00 mm

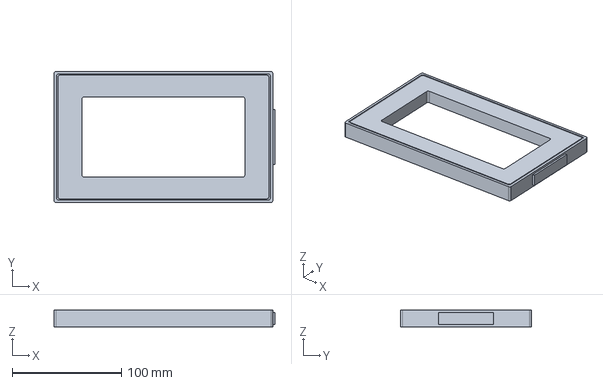
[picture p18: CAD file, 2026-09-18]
blueprints/models/D17/shell_front.step
202.0 x 120.0 x 15.4 mm

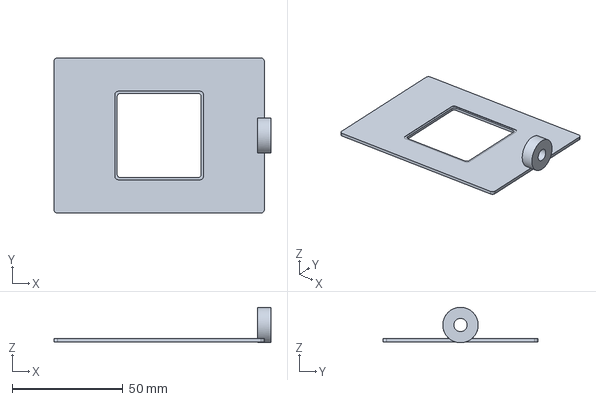
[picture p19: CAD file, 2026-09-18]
blueprints/models/D18/shell_front.step
98.0 x 70.0 x 16.0 mm

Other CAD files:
blueprints/models/B5/shell_back.step
blueprints/models/B7/window_blank.step
blueprints/models/B8/shell_front.step
blueprints/models/B9/shell_front.step
blueprints/models/D16/window_blank.step
blueprints/models/A1/shell_back.stl
blueprints/models/A1/shell_front.step
blueprints/models/A1/shell_front.stl
blueprints/models/A1/window_blank.step
blueprints/models/A1/window_blank.stl
blueprints/models/A2/shell_back.step
blueprints/models/A2/shell_back.stl
blueprints/models/A2/shell_front.stl
blueprints/models/A2/window_blank.step
blueprints/models/A2/window_blank.stl
blueprints/models/A3/rib_cage.step
blueprints/models/A3/rib_cage.stl
blueprints/models/A3/shell_back.step
blueprints/models/A3/shell_back.stl
blueprints/models/A3/window_blank.stl
blueprints/models/A3/window_cartridge.step
blueprints/models/A3/window_cartridge.stl
blueprints/models/A4/shell_back.stl
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

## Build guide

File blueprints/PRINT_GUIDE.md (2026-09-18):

# Nereid — Print & Prototype Guide

All **18** designs have been built as CAD solids:

```text
blueprints/models/<ID>/
  *.stl          # FDM / SLA print
  *.step         # CNC / CAD import
  MANIFEST.json  # part list + print notes
```

**56 STL + 56 STEP** files (~12 MB). Rebuild anytime:

```bash
python blueprints/cad/build_all.py
```

## Print settings (prototype shells)

| Setting | Recommendation |
|---|---|
| Material | PETG or ASA (not PLA for dunk tests) |
| Perimeters | 4–6 |
| Infill | 40–100% (walls matter more than infill) |
| Layer | 0.16–0.20 mm |
| Seams | Orient mating faces up; sand O-ring lands |
| Post | Marine epoxy or silicone on outer seams; COTS O-rings |

Window blanks are **dimensional stand-ins**. Install real glass / PC / spinel from each design BOM before any serious pressure work.

## What each design prints

| ID | Printed parts | Buy / make separately |
|----|---|---|
| A1–A2, A4, B5–B9 | front, back, window blank | load cells / sensors, glass, BLE, seals |
| A3 | rib cage, cartridge, back, window | same + captive M3 screws |
| C10–C13 | front (w/ control bay), back, window | switches, encoder, IMU, PTT, boots |
| C11 | + tether_puck | marine bulkhead + cable |
| D14 | rigid bezel, fabric pattern plate | aramid/TPU body, RF weld |
| D15 | oil shell + lid | silicone oil, diaphragm, OLED — **not FDM-rated to 100 m** |
| D16 | A1 shells + foam_collar | syntactic foam cast or light filament |
| D17 | landscape shells + MOLLE back | dome keys, harness |
| D18 | gauntlet shells | compass repeater, strap |

## Assembly order (all rigid designs)

1. Dry-fit front + back; confirm phone cavity (~147×71×8 mm class).
2. Seat O-rings; clamp without window; leak-check with soapy air.
3. Install electronics per BOM (sensors → PCB → battery → BLE).
4. Bond / seat real window; re-check seal.
5. Pressure pot to **1.5×** design depth (air) before water.
6. Only then dunk / pool test.

## Safety

These are **digital prototypes**. They are **not** certified for immersion, diving, or life-critical use. Oilfill-100 and Titan-20 especially need PE-rated processes (metal / composite / optical) beyond desktop FDM.

## Gallery

Serve the folder and open the design pages:

```bash
npx --yes serve blueprints
```

Each design page lists STL/STEP download links from its `MANIFEST.json`.

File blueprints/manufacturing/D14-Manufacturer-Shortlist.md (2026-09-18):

# D14 Rolltop — Manufacturer Shortlist

Research date: 2026-09-18. Public OEM capability pages only — **get quotes before treating as committed**.

Interactive version: canvas `d14-manufacturer-shortlist.canvas.tsx`

## The important constraint

D14 is a **hybrid**:
1. Soft RF-welded TPU-aramid body + roll-top  
2. Rigid force-sensed bezel (glass + 4 load cells + BLE)

Almost no phone-pouch factory will build (2). Split the BOM.

| Path | When to use |
|---|---|
| **A — Split BOM** | Real D14. Soft OEM + your CNC bezel + your electronics |
| **B — Window clone** | Fast campus demos: clear TPU touch film, no load cells |
| **C — US RF shop** | P1 (8–12 pcs) welding fabric to your CNC flange |

## Tier 1 — Contact this week

| Company | Location | Capable of | Willingness | MOQ cue | Contact |
|---|---|---|---|---|---|
| **Vancharli Outdoor** | Quanzhou, CN | RF-weld TPU/PVC phone pouches, roll-top, touch window, OEM engineering | High | ~100 custom | service@vancharli.com · +86 187 5041 0800 · vancharlioutdoor.com |
| **Szoneier** | CN | OEM dry/wet bags, RF/heat weld, TPU, fast samples | High | ~100; samples ~10–14d | szoneier.com |
| **KeepDryBag** | Quanzhou, CN | HF/RF dry bags, IPX6–8, welding jigs | High | Custom ~300–500 | keepdrybag.com |
| **SealWerks** | Illinois, US | RF weld TPU/PVC/urethane; **prototypes** | Med–High | Quote / short run | radiofrequencywelding.com · 847-439-4565 |
| **Carolina CoverTech** | South Carolina, US | RF weld + heat seal + sewing; in-house dies; proto→volume | Med–High | Quote | carolinacovertech.com |

## Tier 2 — Volume backups

| Company | Notes |
|---|---|
| HoneyDryBag / Dawnjoint | Phone pouches OEM; MOQ 500; often ABS frame openings |
| Tianjin Sijia | High-volume IPX8 TPU/PVC pouches; demand real test reports |
| XMBAG (Xiamen) | TPU/nylon pouches; MOQ 500; 40–50d lead |
| DERFLEX | Coated textiles + dry bag OEM; confirm finished-bag vs roll goods |
| Vinyl Technology (CA) | US mil-grade RF dry bags; likely expensive for IBC volume |

## Practical recommendation

1. **This week:** RFQ Vancharli + Szoneier + KeepDryBag (Path A pricing at 100/250).  
2. **Same week:** Quote SealWerks **or** Carolina CoverTech for Path C P1 hybrids (your CNC bezel + their weld).  
3. **Do not** ask Asia OEMs to integrate load cells on the first email — they will pivot you to a capacitive clear pouch (Path B). Use Path B only if you consciously want a demo SKU.

## RFQ email

```
Subject: RFQ — custom roll-top phone dry pouch, RF-weld to rigid bezel flange (10 pcs sample → 100–250)

We are developing a soft-goods phone dry pouch (Nereid D14 / PocketVault). Need OEM capability for:
(1) TPU-coated nylon/aramid body
(2) RF/HF weld of body to a rigid polymer bezel with continuous seal lip (we supply CNC bezel STEP for samples)
(3) Roll-top closure: 3 folds + dual side-release buckles
(4) Bezel window opening 148×70 mm (glass/sensors by us unless you quote window bond)

Please quote: 10 prototypes; MOQ for 100 and 250; lead time; TPU grade options; air/immersion test method.

Attachments: bezel STEP, dimension sheet, fold spec.
Target: US campus / outdoor retail.
```

## Attachments to send

- `blueprints/models/D14/rigid_bezel.step`
- Outer envelope 175×95×40 mm; aperture 148×70
- Fold spec: 3 rolls minimum + dual buckles
- Material target: TPU-coated 500D; no stitches below waterline

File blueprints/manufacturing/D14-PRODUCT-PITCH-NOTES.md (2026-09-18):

# D14 Rolltop — Product Proposal Speaker Notes

**Runtime:** 10 minutes presenting + 15–20 minutes for objections and the decision  
**Deck:** `blueprints/d14-product-pitch.html` — `←` `→` navigate · `N` presenter notes · `A` jump to appendix · `F` fullscreen  
**Leave-behind:** `blueprints/d14-product-pitch-brief.html` (print, send 24–48 h ahead as a pre-read)

This is a **product adoption decision**, not a manufacturing budget vote. If the room turns to P1 dollars, switch to `d14-approval.html`.

---

## Why the deck is built this way

The structure follows four evidence-backed practices rather than a generic template.

| Practice | Source | What it changed here |
|---|---|---|
| **BLUF** — lead with the decision request in the first 30 seconds | Executive-communication standard for internal decision meetings | The ask moved from slide 12 to slide 1 |
| **Assertion–evidence slides** — sentence headline stating the takeaway, supported by visual evidence instead of bullet lists | Alley & Garner, Penn State; 110-student study found significantly better comprehension, fewer misconceptions, lower cognitive load, stronger delayed recall (p < .01) | Every headline is now a claim, not a topic label |
| **Strategic narrative** — name the change, name the enemy, tease the promised land, then product, evidence last | Raskin's five-element sales narrative | Slides 3–8 reordered; product no longer opens the deck |
| **Contrast / sparkline** — alternate "what is" and "what could be," and name resistance directly | Duarte | Added the enemy slide, the promised-land slide, and an explicit trade-offs slide |
| **Core deck + appendix** — 10–12 core slides, detail pulled on request | Current pitch-deck convention | Spec, cost bands, and risk register moved to appendix |

The trade-offs slide is the one most proposals omit. Naming what a yes costs — before anyone asks — is what makes the recommendation credible.

---

## Before you walk in

- [ ] Send the leave-behind as a pre-read 24–48 hours ahead
- [ ] Pre-socialize with whoever the decider trusts; walk in with the objections already known
- [ ] Click through the deck once cold, fullscreen
- [ ] Know the three numbers without looking: **$19.99 MSRP · ~$10 wholesale · 8–15 doors**
- [ ] Know the honest limit: the load-cell D14 does **not** clear $19.99 until quotes say otherwise
- [ ] Never say IPX8. Say dunk-pass serials.

---

## Timed script

### 1 — The ask (30 sec)
No warm-up, no agenda slide. “I'm asking for one decision today: adopt D14 Rolltop as our flagship product, and fund the RFQ plus demo build, so we can open eight to fifteen wholesale doors before December 16.”

**Then pause.** Let them register that this is a decision meeting.

### 2 — Bottom line (45 sec)
The whole proposal on one page: ask, what it buys, the numbers. If someone is ready to approve here, jump to trade-offs (slide 10) and close early.

### 3 — What changed (60 sec)
External shift, not our problem. “Phones went everywhere water is, and protection never followed. Fifty-five percent of the people we surveyed already ruined something. Sixty-two percent carry nothing.”

### 4 — The enemy (60 sec) ★
“Our competitor is not an eighty-dollar dry bag. It's a sandwich bag and ‘I'll be careful.’” This reframes price for the whole rest of the meeting — we are not asking anyone to trade down.

### 5 — Promised land (20 sec)
Say it and move. “A counter display that empties, and a buyer who texts us for more. Not a catalog. Not a survey. Reorders.”

### 6 — The product (60 sec)
Now the product, framed as what gets a store to that outcome. Hold up a sample if you have one.

### 7 — How it works (45 sec)
Three beats, fast. The real point: a clerk can demo this in twenty seconds with no training.

### 8 — Evidence (75 sec)
“We didn't guess the price — the buyers set it.” Then volunteer the weakness before anyone finds it: 34% top-2 intent and an 81%-student sample. Volunteering it is what makes the rest credible.

### 9 — Business model (75 sec)
Stores are the customer. Give the keystone math out loud — buyers think in margin, not features. Opening order is deliberately small: week one buys shelf space, not revenue.

### 10 — Trade-offs (90 sec) ★
Name all three costs plainly: the flagship can't be the $19.99 SKU, cases freeze cash, and this shelves the other two products for the window.

**Rehearse this transition out loud:** “Having said all three of those, I still recommend yes.” That sentence has to carry the weight of having heard the costs.

### 11 — Decision (45 sec)
Read what changes at yes. Read what changes at no. **Then stop talking.** The silence is the close — do not fill it.

---

## Appendix — pull only when asked

Press `A` to jump. Three pages: the engineering drawing and spec, modeled cost bands, and the risk register. Do not present these; retrieve them.

---

## Likely objections

| Objection | Answer |
|---|---|
| “Isn't this just a dry bag?” | Dry bags protect the phone by making it unusable. Survey ranked waterproof #1 and touchscreen as the differentiator. |
| “$19.99 with electronics in it?” | No — and I won't claim it. The store SKU is de-featured. The instrumented unit is the demo. Appendix has the bands. |
| “Your sample is all students.” | Correct, 81%. That's why we start campus-adjacent doors and not a regional chain. |
| “34% intent is weak.” | Agreed, and that's why the model is demo-led wholesale rather than packaging and ads. |
| “Why not sell direct on Instagram?” | Brand proof only. Revenue is store reorders. Stores get MAP protection or they won't stock us. |
| “Is it waterproof?” | The drawing says water-resistant. It gets the waterproof hangtag only after lot dunk-QC passes. |
| “What about the wallet roll-up?” | That was locked as v1 in `DECISION.md`. This proposal asks to change that. One SKU for this window — that's trade-off three. |
| “What does this cost us?” | RFQ plus demo serials now. Production tooling and inventory are a separate, later vote. |

---

## Packet

| Artifact | Path |
|---|---|
| Deck | `blueprints/d14-product-pitch.html` |
| Leave-behind / pre-read | `blueprints/d14-product-pitch-brief.html` |
| These notes | `blueprints/manufacturing/D14-PRODUCT-PITCH-NOTES.md` |
| Wholesale business model | canvas `pocketvault-business-model-canvas.canvas.tsx` |
| Manufacturing vote (separate meeting) | `blueprints/d14-approval.html` |

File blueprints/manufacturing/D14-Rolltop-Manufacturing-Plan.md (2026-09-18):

# D14 Rolltop — Manufacturing Plan (Rev A)

Companion to the interactive plan canvas. Source of truth for geometry:
`blueprints/models/D14/`, `designs.js` (D14), `cad/build_all.py` → `rolltop_bezel()`.

**Approval packet for decision meeting**

| Artifact | Path |
|---|---|
| Slide deck (present this) | `blueprints/d14-approval.html` |
| One-page leave-behind (print) | `blueprints/d14-approval-brief.html` |
| Speaker notes + Q&A | `blueprints/manufacturing/D14-SPEAKER-NOTES.md` |
| This plan | `blueprints/manufacturing/D14-Rolltop-Manufacturing-Plan.md` |

**Motion:** Authorize **P1 only** — CNC/soft-tool bezels, RF-weld fabric bodies, window + load-cell stack, dunk proof 1.5× — ceiling **$18k**, ~**5 weeks**, success = **≥5 units dunk-pass**. Not authorizing production molds, inventory, or IPX8 claims.

## Critical warning

**Printed bezels are fit-check / soft-tool only until FAIR.** Production depth rating (6 m) requires RF-welded TPU-aramid to a qualified flange, real glass, calibrated load cells, and dunk proof at **1.5× design**. Not certified for dive use until that program passes. Campus demos only on passed serials.

## Product snapshot

| Item | Value |
|---|---|
| Envelope (deployed) | 175 × 95 × 40 mm |
| Aperture | 148 × 70 mm |
| Body | 500D aramid + TPU coat |
| Bezel | Rigid PPA/Mg + fabric clamp flange |
| Sensing | A1-style 4 load cells in bezel |
| Closure | 3 rolls + 2 side-release buckles |
| Mass target | 122 g |
| Design depth | 6 m |
| Packed volume | ~40% of rigid Nereid cases |

## Principle

Soft fabric body absorbs impact and collapses for packability. The only hard assembly is the force-sensed window bezel. Waterproofing is owned by (1) continuous RF weld at the bezel lip and (2) trained roll-and-clamp closure. Phone remains usable through glass.

**Known weak point:** hard bezel edge under direct impact — pad / bumper before calling structure done.

## Mass budget (122 g)

| Part | Mass |
|---|---|
| Aramid/TPU body + roll | 34 g |
| Bezel + window + load cells | 61 g |
| Battery + BLE | 16 g |
| Buckles + misc | 11 g |

## CAD handoff

| File | Use |
|---|-----|
| `models/D14/rigid_bezel.step` | Bezel CNC / mold cavity |
| `models/D14/window_blank.step` | Glass stand-in → real glass |
| `models/D14/fabric_cut_pattern.step` | Pattern reference / DXF export |
| `models/D14/*.stl` | FDM fit-check bezel only |

Rebuild: `python blueprints/cad/build_all.py`

## BOM (summary)

1. TPU-coated 500D aramid body (RF-weldable)  
2. Rigid bezel with continuous seal lip / flange  
3. Glass 1.5 mm + silicone mount  
4. Four load cells + flex / PCB  
5. Roll bar / clamp strip  
6. Dual side-release buckles + webbing  
7. Battery + BLE in dry pocket  
8. Edge bumper / pad (recommended)  
9. Care card: 3-fold diagram  

## Process phases

0. Engineering freeze (STEP, DXF pattern, fold spec)  
1. Materials RFQ (2 sources fabric, buckles, glass, cells)  
2. Bezel manufacture (FAIR flange flatness ≤ 0.05 mm)  
3. Fabric cut + RF weld to lip (peel coupons)  
4. Window + load cells (dry calibration)  
5. Electronics dry pocket  
6. Fold training (&lt;15 s to seal)  
7. Dunk proof 1.5× design  
8. Serialize + fold card + care kit  

## Assembly checklist

1. Incoming inspect bezel flange (flatness, finish)  
2. Cut fabric per pattern; mark fold lines  
3. RF-weld body to bezel lip; dye-pen inspect  
4. Peel coupon from same weld lot  
5. Install glass + four load cells; dry cal  
6. Mount battery/BLE dry pocket  
7. Install buckles + roll bar  
8. Operator fold drill ×10  
9. Dunk 1.5× timed; inspect fog/weep  
10. Log serial, peel, fold time, dunk result  
11. Pack with care card  

## Test gates

| Test | When | Pass |
|---|---|---|
| Dimensional FAIR | First article | Flange / pockets vs STEP |
| Peel strength | Every weld lot | ≥ process minimum (set in P1) |
| Dry force cal | 100% | Touch usable dry |
| Fold time | 100% | ≤15 s trained |
| Dunk 1.5× | 100% | No weep / no fog |
| Gloved wet touch | Sample / lot | Usable under water film |
| Sand / abrasion | Sample | No weld lift |
| Drop on bezel edge | Sample | Bumper decision |

## Prototype ladder

| Gate | Build | Allowed |
|---|---|---|
| P0 | Print bezel + fabric mock | Fit only |
| P1 | CNC bezel + RF weld + dunk | Bench / tank proof |
| P2 | Live cells + campus dunk demos | Supervised demos |
| P3 | Production tooling | After P1/P2 pass |
| P4 | Production SPC | Peel + dunk yield |

## Cost planning bands (not quotes)

- P1 authorization: **$7k–$18k** (midpoint ~$11k)  
- Later NRE bezel mold: roughly **$5k–$20k** (separate vote)  
- Unit COGS @ 100–250: planning **$8–$22** depending on cells/glass (re-estimate after P1 actuals)

## Open risks

- RF pinholes at lip → peel + dye-pen every lot  
- User under-rolls → stencil + training card; treat as product risk  
- Bezel edge crack → bumper options in P1  
- Weak wet touch → dunk cal reject gate  
- Abrasion → sand sample before P3  
- COGS vs $19.99 list → price/scope gate before inventory  

## Maintenance

Rinse after salt; inspect weld lip; re-train fold if new user. Do not machine-dry on high heat. Replace if glass spidered or weld lifted.

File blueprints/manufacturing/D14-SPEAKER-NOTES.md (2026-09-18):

# D14 Manufacturing Approval — Speaker Notes

**Runtime:** 12–14 minutes + 8–10 minutes Q&A  
**Deck:** `blueprints/d14-approval.html` (← →, F fullscreen)  
**Leave-behind:** `blueprints/d14-approval-brief.html` (print 1 page)  
**Full plan:** `blueprints/manufacturing/D14-Rolltop-Manufacturing-Plan.md`

---

## Before you walk in

- [ ] Open deck fullscreen; click through once cold
- [ ] Print 1 leave-behind per decision-maker
- [ ] Have `D14-rolltop.mp4` ready if someone asks “show me”
- [ ] Know your number: **~$11k midpoint / $18k ceiling / 5 weeks / ≥5 units dunk-pass**
- [ ] Decide your walk-away: if they only approve “sew it yourself,” that is a **no** — RF weld process must be funded

---

## Timed script

### Slide 1 — Title (45 sec)
“I’m asking for one decision: authorize **P1 manufacturing** for D14 Rolltop — bezels, RF-weld fabric bodies, window stack, and dunk proof — so we prove the soft-goods seal before production tooling.”

### Slide 2 — Stakes (60 sec)
“People forget dry bags. Rigid cases only work if they came on the trip. D14 packs to ~40% of a hard shell and still lets you use the phone through glass. Without a soft-goods path, we only know how to machine boxes.”

### Slide 3 — Insight (90 sec)
“Hard where it senses, soft everywhere else. TPU-aramid RF-welded to a force-sensed bezel. Three rolls and dual buckles. Manufacturing owns the weld and the fold — not wall thickness.”

### Slide 4 — Spec (45 sec)
“Spec is frozen enough to cut fabric and machine flanges: 175×95×40, 148×70 aperture, 122 g mass stack.”

### Slide 5 — Evidence (45 sec)
“CAD, BOM, mass, explode stills, lifestyle pack shot, film — already exist. This vote is authorization to prove, not invention.”

### Slide 6 — Process (75 sec)
“Two product truths: **RF weld integrity** and **fold discipline**. Undersell either and the dunk demo becomes a public failure.”

### Slide 7 — Ladder (75 sec) ★
“I am **not** asking for production dies today. P1 is the cheap fail. P3 tooling is a separate vote after dunk evidence.”

### Slide 8 — Phases (40 sec)
“Nine phases, exit-gated. Fold training before dunk. Peel coupons every weld lot.”

### Slide 9 — Money (60 sec)
“Authorization **$7–18k**, midpoint **~$11k**. Excluded: production molds, inventory, certification filing.”

### Slide 10 — Schedule (40 sec)
“Five weeks to go/no-go. Kill: flange leak or fold can’t seal. Success: ≥5 dunk-pass with logs.”

### Slide 11 — Risks (60 sec)
“Walk the table — pinholes, under-rolling, bezel edge, wet touch, abrasion, COGS vs $19.99. Each has a P1 mitigation.”

### Slide 12 — Integrity (45 sec)
“After P1 we claim demo-ready architecture — **not** IPX8. Dunk demos only on passed serials.”

### Slide 13 — Ask (60 sec)
Read Approve box. Then: “Hold only if you reject soft-goods as a thesis — not because the plan isn’t ready.”

### Slide 14 — Close (20 sec)
“Pack flat. Roll shut. Prove the weld. Yes or no on P1?”

**Stop talking.**

---

## Likely Q&A

| Objection | Answer |
|---|---|
| “Just buy generic dry bags.” | They fog, don’t sense touch, and aren’t a product story. D14 is usable through glass + packable. |
| “RF weld is exotic / expensive.” | It’s standard soft-goods waterproofing. P1 funds shop time to prove our flange geometry. |
| “Users won’t roll three times.” | That’s why fold marks + training card are P1 deliverables — and a kill risk we named. |
| “Bezel will crack.” | Known weak point. P1 includes bumper options and drop samples before we call structure done. |
| “Why not D15 depth instead?” | Different thesis. D14 is availability + campus dunk demos. D15 is depth moat. Separate votes. |
| “Can we sew instead of RF?” | Stitch holes below waterline are a leak factory. RF or heat-weld only for P1. |
| “$18k for fabric?” | Ceiling includes bezels, cells, glass, electronics, dunk — not just cloth. Midpoint ~$11k. |
| “Is this IPX8?” | No. We will not claim that from P1. |

---

## Closing line if the room stalls

“I’m not asking you to believe the bag never leaks. I’m asking you to fund the dunks that can prove the weld — before we ever demo on campus.”

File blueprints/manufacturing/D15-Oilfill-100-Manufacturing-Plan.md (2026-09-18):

# D15 Oilfill-100 — Manufacturing Plan (Rev A)

Companion to the interactive plan canvas. Source of truth for geometry:
`blueprints/models/D15/`, `designs.js` (D15), `cad/build_all.py` → `oilfill_housing()`.

**Approval packet for decision meeting**

| Artifact | Path |
|---|---|
| Slide deck (present this) | `blueprints/d15-approval.html` |
| One-page leave-behind (print) | `blueprints/d15-approval-brief.html` |
| Speaker notes + Q&A | `blueprints/manufacturing/D15-SPEAKER-NOTES.md` |
| This plan | `blueprints/manufacturing/D15-Oilfill-100-Manufacturing-Plan.md` |

**Motion:** Authorize **P1 only** — CNC housings, fill station, hydro proof — ceiling **$28k**, ~**6 weeks**, success = **≥3 units at 15 bar**. Not authorizing molds, inventory, or certification claims.

## Critical warning

**Desktop FDM is fit-check only.** 100 m rating requires PE-rated PPA/PEI housing,
qualified oil/diaphragm, and hydrostatic proof at **15 bar (1.5×)**. Not certified
for dive use until that program passes.

## Product snapshot

| Item | Value |
|---|---|
| Envelope | 170 × 90 × 35 mm |
| Wall | 1.0 mm PPA (pressure-compensated) |
| Design depth | 100 m → 10 bar |
| Proof | 15 bar |
| Mass target | 178 g |
| Sensing | Physical keys / encoder (phone screen unusable in oil) |
| Readout | Separate sealed OLED + BLE MCU |

## Principle

Rolling silicone diaphragm equalizes internal silicone-oil pressure with ambient
hydrostatic pressure so ΔP across the thin shell ≈ 0. Phone is immersed; UI is
OLED + keys only.

**Reservoir:** size ≥ 40 mL free volume for ~400 mL oil over −32…+71 °C
(CTE ~0.00095/°C × 103 °C), plus margin.

## CAD handoff

| File | Use |
|---|-----|
| `models/D15/oil_shell.step` | Body — CNC / mold |
| `models/D15/oil_lid.step` | Lid |
| `models/D15/*.stl` | FDM mock only |
| `models/D15/MANIFEST.json` | Volumes + notes |

Rebuild: `python blueprints/cad/build_all.py`

## BOM (summary)

1. PPA/PEI oil shell + lid  
2. Rolling VMQ diaphragm + retainer  
3. Silicone dielectric oil (~350–400 mL)  
4. Expansion reservoir / bladder (≥40 mL)  
5. Fill/bleed valve  
6. O-rings (double preferred)  
7. Sealed OLED + MCU + BLE  
8. Encoder + hat keys + boots  
9. Battery (prefer dry bay)  
10. Silicone cradle, 316 SS hardware  

Mass budget: shell 28 + oil/diaphragm/reservoir 52 + OLED/MCU 34 + keys 16 + battery/BLE 16 + seals/misc 32 = **178 g**.

## Process phases

0. Engineering freeze (STEP, oil calc, seals)  
1. Tooling & materials RFQ  
2. Housing manufacture (mold or CNC)  
3. Diaphragm, reservoir, valve, OLED bay  
4. Electronics SMT + firmware  
5. Dry assembly + air leak test  
6. Vacuum degas → oil fill → bleed  
7. Hydro proof 15 bar → working 10 bar  
8. Serialize, maintenance kit, pack  

## Assembly checklist

1. Incoming inspect glands (Ra ≤ 0.8 µm)  
2. Inserts / fasteners  
3. OLED dry-bay seal + leak check  
4. MCU, keys, battery feedthroughs  
5. Diaphragm + retainer; free stroke  
6. Cradle + phone clearance  
7. O-rings + lid; **air leak before oil**  
8. Degas oil; fill to mid-stroke diaphragm  
9. Bleed bubbles; weigh; log oil mass  
10. Firmware + BLE pair  
11. Hydro 15 bar / 15 min; then 10 bar functional  
12. Pack with top-off syringe kit  

## Test gates

| Test | When | Pass |
|---|---|---|
| Dimensional FAIR | First article | Glands/port vs STEP |
| Dry leak | 100% | 1 bar soap / decay |
| Hydro proof | 100% | 15 bar, 15 min, no weep |
| Hydro working | 100% | 10 bar + UI |
| Thermal soak | Lot sample | Diaphragm within stops |
| Field immersion | Pilots | Logged progression |

## Prototype ladder

| Gate | Build | Allowed |
|---|---|---|
| P0 | FDM dry | Fit only |
| P1 | CNC + oil | Bench hydro |
| P2 | Full electronics | Pool ≤ 5 m supervised |
| P3 | Molded samples | Quarry → rating |
| P4 | Production | After cert path |

## Cost planning bands (not quotes)

- NRE tooling + station + bring-up: roughly **$18k–$55k**  
- COGS @ ~100 pcs: roughly **$80–$170**/unit  

## Open risks

- Oil compatibility with phone seals / USB-C → 30-day soak on sacrificial units  
- Diaphragm fatigue → cycle test + inspect interval  
- User expects phone screen → OLED UX demos before sale  
- Undersized reservoir → measure oil mass then re-freeze volume  
- Mold knit lines on O-ring lands → mold-flow + gate plan  
- GF PPA killing BLE → RF window keep-out  

## Maintenance

Ship 20 mL oil + valve adapter. Top-off interval estimate 6–12 months. Fogged OLED
or oil weep → stop use, RMA.

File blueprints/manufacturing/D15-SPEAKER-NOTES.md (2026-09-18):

# D15 Manufacturing Approval — Speaker Notes

**Runtime:** 12–14 minutes + 8–10 minutes Q&A  
**Deck:** `blueprints/d15-approval.html` (← →, F fullscreen)  
**Leave-behind:** `blueprints/d15-approval-brief.html` (print 1 page)  
**Full plan:** `blueprints/manufacturing/D15-Oilfill-100-Manufacturing-Plan.md`

---

## Before you walk in

- [ ] Open deck fullscreen; click through once cold
- [ ] Print 1 leave-behind per decision-maker
- [ ] Have `D15-oilfill-100.mp4` ready if someone asks “show me”
- [ ] Know your number: **~$18k midpoint / $28k ceiling / 6 weeks / ≥3 units at 15 bar**
- [ ] Decide your walk-away: if they only approve FDM, that is a **no** — say so politely

---

## Timed script

### Slide 1 — Title (45 sec)
“I’m asking for one decision: authorize **P1 manufacturing** for D15 Oilfill-100 — CNC housings, oil-fill process, and hydrostatic proof — so we can prove depth physics before we spend mold money.”

### Slide 2 — Stakes (60 sec)
“Recreational cases stop at snorkel-to-sport depths by thickening walls. D15 is the jump to **100 m**. Without a manufacturing path it’s a render. With P1, we find out if the architecture is real.”

### Slide 3 — Insight (90 sec)
“The bet is equalize, don’t fight. Rolling diaphragm compresses silicone oil until shell ΔP is ~0. That lets us keep **1 mm walls**. Honest trade: phone screen dies in oil; UI is sealed OLED + keys.”

*Pause. Let them object here if they hate the trade — better now than later.*

### Slide 4 — Spec (45 sec)
“Spec is frozen enough to machine: envelope, port, OLED bay, mass budget 178 g. CAD STEP is already exported.”

### Slide 5 — Evidence (45 sec)
“We’re not pitching a sketch. Geometry, BOM, mass stack, explode stills, and a product film exist. This meeting is about **authorization to prove**, not invention.”

### Slide 6 — Math (75 sec)
“Two numbers matter: **≥40 mL reservoir** from thermal expansion math, and **15 bar proof** every unit. Undersize the reservoir and heat kills you. Skip proof and we are lying about depth.”

### Slide 7 — Ladder (75 sec) ★
“Critical: **I am not asking for mold steel today.** P1 is the cheap fail. P3 tooling is a *separate* vote after proof.”

### Slide 8 — Phases (40 sec)
“Nine phases, each with an exit gate. Air leak **before** oil. That’s how we don’t waste oil diagnosing a bad O-ring.”

### Slide 9 — Money (60 sec)
“Authorization band **$10–28k**, planning midpoint **~$18k**. Explicitly excluded: production molds, inventory, certification filing.”

### Slide 10 — Schedule (40 sec)
“Six weeks to a go/no-go memo. Kill criterion: cannot hold 15 bar. Success: ≥3 units pass with logged oil mass.”

### Slide 11 — Risks (60 sec)
“Walk the table. Oil/phone chemistry, diaphragm fatigue, UX rejection of no touchscreen — each has a P1 mitigation. We named the killers before you did.”

### Slide 12 — Integrity (45 sec)
“After P1 we claim bench-validated architecture — **not** a consumer 100 m cert. Overclaiming is how programs get shut down later. We won’t.”

### Slide 13 — Ask (60 sec)
Read the Approve box verbatim. Then: “If you hold because you reject depth as a thesis, say that. Don’t hold because the plan isn’t ready — it is.”

### Slide 14 — Close (20 sec)
“Make pressure disappear — then prove it. Yes or no on P1?”

**Stop talking. Let silence work.**

---

## Likely Q&A (have answers cold)

| Objection | Answer |
|---|---|
| “Why not just thicken the case?” | Mass and optic cost explode; still a dry vessel. Compensation is the only light path to 100 m. |
| “Phone in oil will brick.” | P1 includes sacrificial soak + CoC oil only. If chemistry fails, we kill before tooling. |
| “Nobody wants a device without a phone screen.” | Possible — that’s why OLED UX is a P2 gate before mold steel. Depth buyers accept instruments; we test that. |
| “$28k is a lot for students / early stage.” | Compared to a bad mold ($8–25k) that leaks, P1 is insurance. Ceiling, not target. |
| “Can FDM prove this?” | No. FDM is P0 fit only. Saying otherwise is how you fail the pot and lose trust. |
| “Is this certified?” | No. We will not claim certification. P1 proves physics and process. |
| “Why D15 not Rolltop?” | Different jobs. Rolltop is always-with-you dry carry. D15 is depth. This vote is the depth manufacturing path. |
| “What if P1 fails?” | We stop. Write the autopsy. No P3. That *is* success of the governance model. |

---

## Closing line if the room stalls

“I’m not asking you to believe D15 works. I’m asking you to fund the test that can prove me wrong cheaply.”

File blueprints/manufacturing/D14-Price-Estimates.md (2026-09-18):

# D14 Rolltop — Price Estimates

**Status:** Modeled planning numbers (±30–50%), **not firm supplier quotes**.  
**Date:** 2026-09-18  
**Canvas:** `d14-price-estimates.canvas.tsx`

## Headlines

| Scenario | Qty | Low | Mid | High | Mid $/unit |
|---|-----|-----|-----|---|---|
| P1 US hybrid (Path C) | 10 | $7.2k | **~$11.2k** | $16.8k | ~$1,120* |
| Asia pilot (Path A) | 100 | $4.8k | **~$7.8–14.7k** | $12.5k+ | ~$78–147 |
| Asia bridge (Path A) | 250 | $8.5k | **~$14.5–23k** | $22k+ | ~$58–93 |
| Path B demo (no load cells) | 250 | — | **~$2–6k** | — | **~$8–25** |

\*Includes shared NRE/setup amortized into program; variable build ~$520/unit mid.

**P1 approval ask stays valid:** ceiling **$18k**, planning mid **~$11k**.

## Soft body (FOB China, published anchors)

| Product type | @100 | @250–500 |
|---|---|---|
| Stock/simple TPU phone pouch | $3–6 | $1.50–4.25 |
| Custom RF roll-top body | $8–18 | $5–12 |
| Custom + weld to hard flange | $12–28 | $8–18 |

Published comps: ~$3.01 @500, $4.25 @500 OEM, $1.85 @600+ generic.

## Bezel

| | @10 | @100 | @250 |
|--|-----|---|---|
| CNC | $120–350 | $35–90 | $25–70 |
| Soft mold NRE | — | $3–8k | $3–8k |
| Molded piece | — | $4–12 | $2.50–8 |

## Electronics (4 cells + BLE)

| | @10 | @100 | @250 |
|--|-----|---|---|
| Subtotal | $74–222 | $36–96 | $28–75 |

## Margin reality @ $19.99

- Path B (clear TPU): clears campus math.  
- True load-cell D14 @ ~$60–90 landed: needs **$29.99–$49.99** ASP or direct-only sales.

## Next step

Send RFQs (template in manufacturer shortlist). Replace this model within 1–2 weeks when Vancharli / Szoneier / SealWerks reply.
